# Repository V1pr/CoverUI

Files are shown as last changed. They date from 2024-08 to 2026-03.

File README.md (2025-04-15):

# CoverUI for [OpenMower](https://github.com/ClemensElflein/OpenMower)

 

## About

This repository contains the firmware files required to use the mowers CoverUI (ButtonBoard).

## Variants

1. Custom DIY CoverUI-PCB which replaces the stock (top-cover) PCB.<br>
 Please check the [Cover UI board assembly instructions](<https://openmower.de/docs/cover-ui-assembly/>) for more detailed infos.<br>
 Also available in [Vermut's Shop](https://shop.devops.care/10-openmower) (as part of his 'Upgrade Kit')
1. Stock YardForce CoverUI for the following models:
   1. Classic 500 (STM32 & GD32 MCU)
   2. Classic 500B (STM32 & GD32 MCU)
   3. SA/SC/NX-Type (10 Buttons, 12 LEDs), PCB labeled with RM-ECOW-V1.0.0 (STM32 MCU)
   4. SA/SC/NX-Type (9 Buttons, 11 LEDs), PCB labeled with RM-ECOW-V1.1.0 (STM32 & GD32 MCU)
   5. NX100i (18 Buttons, 3 LEDs, 256*64 Pixel LC-Display), PCB labeled with RM-EC3-V1.1 (STM32 MCU)
   6. SAxPro (Rev6) 6 Buttons 240*128 Pixel LC-Display (STM32 MCU)
   
    For this, you need to solder some cables and flash a modified firmware to it.<br>
    Please check the detailed [Stock CoverUI Readme](Firmware/CoverUI/YardForce/README.md) (as you've also the option to use your stock 'hall', 'stop' and 'rain' cables).

+1. LegacyHAT, a HAT addon for non-uC original CoverUI (9 Buttons, 11 LEDs), HAT uses an STM32F4xx "black pill" (mind the pill size!) - UNTESTED (yet!)

## License

Distributed under the MIT License. See [LICENSE](LICENSE) for more information.

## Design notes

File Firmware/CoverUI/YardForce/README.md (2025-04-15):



[][contributors-url]
[][forks-url]
[][stars-url]
[][issues-url]
[][license-url]

<!-- CoverUI model images -->
<br />
<div align="center">
  <a href="#hardware-modifications-by-model">
    Classic 500(B)
  </a>
  <a href="README-MOD-YF-SASCNX_RM-ECOW-V1.0.0.md">
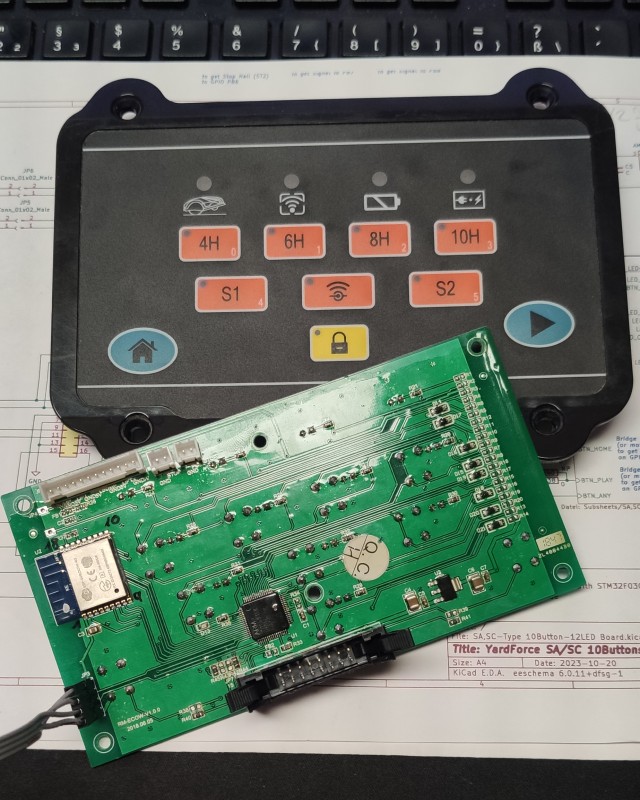
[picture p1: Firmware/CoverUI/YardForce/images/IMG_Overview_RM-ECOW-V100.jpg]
NX80i (10 Buttons, 12 LEDs) SA/SC/NX-Type CoverUI
    
  </a>
  <a href="README-MOD-YF-SASCNX_RM-ECOW-V1.1.0.md">
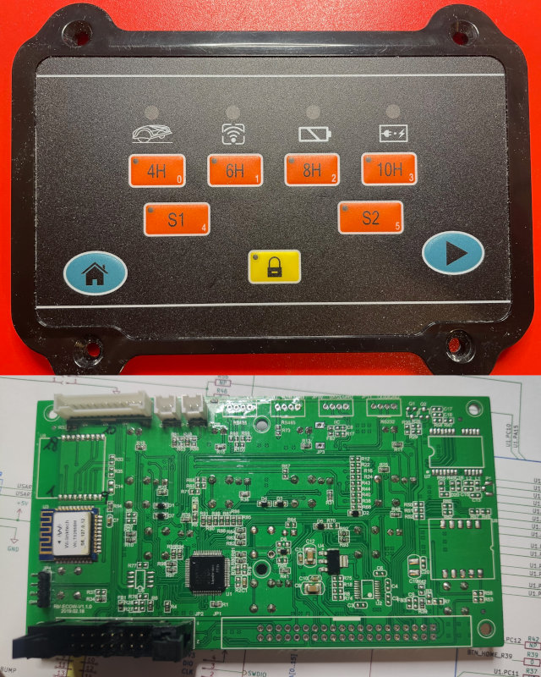
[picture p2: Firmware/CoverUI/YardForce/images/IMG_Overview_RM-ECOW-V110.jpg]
SA650 (9 Buttons, 11 LEDs) SA/SC/NX-Type CoverUI
    
  </a>
  <a href="README-MOD-YF-SASCNX_RM-EC3-V1.1.md">
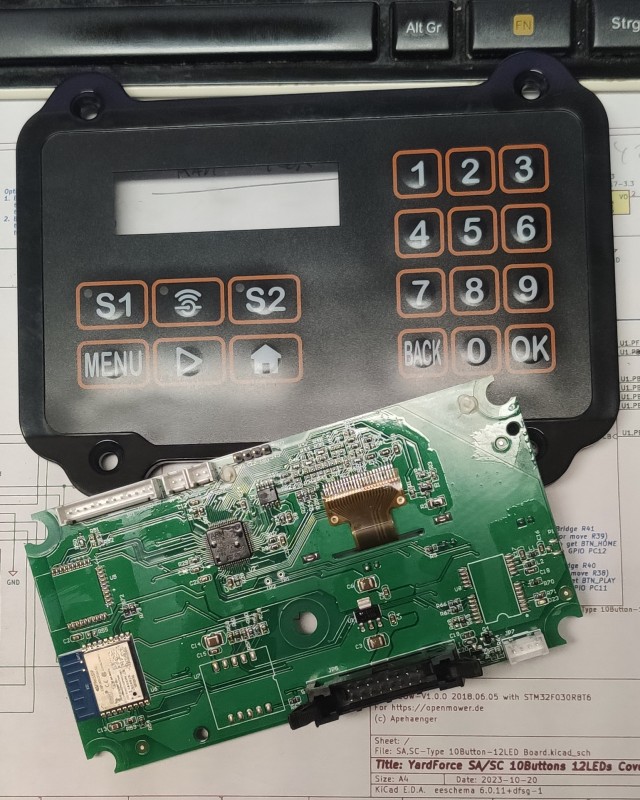
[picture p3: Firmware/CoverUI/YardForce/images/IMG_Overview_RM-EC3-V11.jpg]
NX100i (18 Buttons, 3 LEDs, 256*64 Pixel LC-Display) SA/SC/NX-Type CoverUI
    
  </a>
  <a href="README-MOD-YF-SASC_PRO_HS49067.md">
    SA/SC-PRO-Type (6 Buttons, 240*160 Pixel LC-Display)
  </a>

  <h3 align="center">OM CoverUI Firmware for Stock YardForce PCBs</h3>

  <p align="center">

#### Tested/working with

| YardForce Model | PCB Label | <a href="https://en.wikipedia.org/wiki/Microcontroller">MCU</a> Variant |
| :--- | :---: | :---: |
| Classic 500 | RM-ECOW-V1.3.0, 2020.05.08 | STM32F030R8, GD32F330R8 |
| Classic 500B | RM-ECOW-V1.3.1, 2021.08.09 | STM32F030R8[^1], GD32F330R8 |
| SA/SC/NX-Type (10 Buttons, 12 LEDs) | RM-ECOW-V1.0.0, 2018.06.05 | STM32F030R8 |
| SA/SC/NX-Type (9 Buttons, 11 LEDs)e | RM-ECOW-V1.1.0, 2019.02.18 | STM32F030R8, GD32F330R8 |
| NX100i (18 Buttons, 3 LEDs, 256*64 Pixel LC-Display), SA/SC/NX-Type | RM-EC3-V1.1, 20210619 | STM32F401RC |
| SA/SC-PRO-Type Rev6 (6 Buttons, 240*128 Pixel LC-Display) | HS49067, WYPCB319B | STM32F030RC |

  [^1]: Not yet tested, but it's expected that it will also work flawless

  </p>
</div>

## About The Project

For those, who still have their stock *YardForce (Rev6)* Cover-UI available and want to get it running together with [OpenMower](https://github.com/ClemensElflein/OpenMower), I ported OM's CoverUI <abbr title="Firmware">FW</abbr> functionality to a couple of them (see [Tested/working with](#testedworking-with)).

<p align="right">(<a href="#readme-top">back to top</a>)</p>

## Getting Started

### Prerequisites

* Compatible stock *YardForce* Cover-UI/Button-Board or Display (see [Tested/working with](#testedworking-with))
* Soldering Iron
* ST-Link programmer/debugger

### Hardware Modifications by Model

Every CoverUI model require some hardware modifications.

Please check here, what modifications are required for your CoverUI model:

- [YardForce Classic 500, RM-ECOW-V1.3.0](README-MOD-YF-C500_RM-ECOW-V1.3.0.md)
- [YardForce Classic 500**B**, RM-ECOW-V1.3.1](README-MOD-YF-C500B_RM-ECOW-V1.3.1.md)
- [YardForce SA/SC/NX-Type 10 Buttons, 12 LEDs, RM-ECOW-V1.0.0](README-MOD-YF-SASCNX_RM-ECOW-V1.0.0.md)
- [YardForce SA/SC/NX-Type 9 Buttons, 11 LEDs, RM-ECOW-V1.1.0](README-MOD-YF-SASCNX_RM-ECOW-V1.1.0.md)
- [YardForce NX100i (SA/SC/NX-Type) 18 Buttons, 3 LEDs, 256*64 Pixel LC-Display, RM-EC3-V1.1](README-MOD-YF-SASCNX_RM-EC3-V1.1.md)
- [YardForce SA/SC-PRO-Type 6 Buttons, 240*160 Dot-Matrix-Display, HS49067](README-MOD-YF-SASC_PRO_HS49067.md)

## Flash Firmware

### Programmer/Debugger

You need an ST-Link programmer/debugger like this cheap *ST-Link (V2) clone*:

My ST-Link (V2) clone

There're two generic ways to get the Firmware into your MCU.<br>
Either you flash the binary directly, or you compile it by yourself with [PlatformIO](https://platformio.org/).

### Firmware binaries

1. Goto [Releases](/releases)
2. Download `firmware-stock.zip`
3. Unpack it somewhere

The file name syntax of the included firmware binaries is:  `firmware_<MDL>_<MCU>[_<opt MOD>, ...].bin`

> **Warning**
> Only install the \<MOD> version, for which you also made the required hardware modifications!
> See [Hardware Modifications by Model](#hardware-modifications-by-model)

### ST-Link (flash binary)

> **Note**
> Updated 05/07/2023

It turns out that ST-Link GUI tool is some how flawy, why I recommend to use the `st-flash` console command.

Open a terminal/console, then:

* `st-info --descr` should return either:
  * `F0xx`, which identify your PCB's MCU as a 'STM32F030R8' (i.e. Classic 500)
  * `F1xx Medium-density` or `STM32F1xx_MD` which identify a 'GD32F330R8' MCU (i.e. Classic 500)
  * `F09X` identifies a 'STM32F030RC' MCU (i.e. SAxPRO Display)
* Unplug everything from you stock CoverUI PCB and connect your ST-Link to GND, CLK, DIO and 3V3. Take special attention to hit the '3.3V' pin of your ST-Link!! Now simply:<br>
 `st-flash write firmware_<mdl>_<mcu type>[_<opt mod>, ...].bin 0x08000000` which should log at the end something like 'Flash written and verified! jolly good!'

When done, re-plug your ST-Link and you should see a quick power-on animation.

If st-flash fails with an error like "Flash memory is write protected", we need to unlock it.<br>
I used [OpenOCD][OpenOCD-url] for unlocking it. Try `openocd --version` to check if [OpenOCD][OpenOCD-url] is already installed.

Unlock your flash via:

```openocd -f interface/stlink.cfg -f target/stm32f0x.cfg -c "init" -c "halt" -c "stm32f0x unlock 0" -c "shutdown"```

Now, try again flashing by: `st-flash write firmware_<mdl>_<mcu type>[_<opt mod>, ...].bin 0x08000000`

### PlatformIO

[PlatformIO](https://platformio.org/) is a [Visual Studio Code](https://code.visualstudio.com/) extension. Once installed, do:

- `PlatformIO` (left bar)
- `PIO Home` -> `Open`
- `Open Project` cloned repository branch -> CoverUI/Firmware/CoverUI (contains platformio.ini)
- Wait till tools got loaded (bottom right status info)
- In bottombar click `Switch PlatformIO Project Environment` and choose whatever MCU, MOD & programmer/debugger- probe you use
- Wait till tools got loaded (bottom right status info)
- Finally press `PlatformIO: Upload` (right arrow symbol) in bottombar. After it compiled, linked and uploaded, it should reboot and do a short power-on LED animation.
- If you get an "Error: stm32x device protected", simply upload a second time. Look like I placed the "unlock" command some how to late. 

<p align="right">(<a href="#readme-top">back to top</a>)</p>

<!-- USAGE EXAMPLES -->
## Usage

> **Note**
> Updated 11/07/2023

Once flashed, the CoverUI should show you a quick LED animation when powered on.

### Meaning of the LEDs:

| C500(B) | SA/SC/NX-Type,<br>9&nbsp;Buttons, 11&nbsp;LEDs | SA/SC/NX-Type,<br>10&nbsp;Buttons, 12&nbsp;LEDs | NX100i<br>(SA/SC/NX-Type),<br>18&nbsp;Buttons, 3&nbsp;LEDs,<br> 256*64 Pixel LC-Display | SA/SC-PRO<br>(240*160 Pixel LC-Display) | Remark |
| :-------: | :-----: | :-------: | :----: | :----: | ----- |
| 2hr&nbsp;-&nbsp;8hr | 4H&nbsp;-&nbsp;10H | 4H&nbsp;-&nbsp;10H | <img src="images/lcd.svg" width=15% height=15%> | <img src="images/lcd.svg" width=15% height=15%> | 4 digi GPS quality progressbar. Blink = No GPS-Fix
| S1 | :heavy_check_mark: | :heavy_check_mark: | <img src="images/brain-solid.svg" width=15% height=15%> | <img src="images/brain-solid.svg" width=15% height=15%> | ROS State:<br><b>On</b> = Running (idle)<br> <b>Blink-slow</b> = Autonomous mode (mowing, (un-)docking)<br><b>Blink-fast</b> = Area recording<br><b>Off</b> = ROS not running |
| S2 | :heavy_check_mark: | :heavy_check_mark: | <img src="images/lcd.svg" width=15% height=15%> | <img src="images/lcd.svg" width=15% height=15%> | ROS Sub-State:<br><b>On</b> = not used<br> <b>Blink-slow</b> = Docking or Record-Outline<br><b>Blink-fast</b> = Undocking or Record-Obstacle<br><b>Off</b> = Idle or Mowing |
| Lifted | :heavy_check_mark: | :heavy_check_mark: | <img src="images/car-burst-solid.svg" width=15% height=15%> | <img src="images/car-burst-solid.svg" width=15% height=15%> | Emergency:<br><b>On</b> = No heart beat for more than 0.5s?!?<br> <b>Blink-slow</b> = Lifted or tilted<br><b>Blink-fast</b> = Stop button pressed<br><b>Off</b> = No Emergency |
| Wire | WLAN | WLAN | <img src="images/satellite-dish-solid.svg" width=15% height=15%> | <img src="images/satellite-dish-solid.svg" width=15% height=15%> | GPS Quality:<br><b>On</b> = \<25%<br><b>Blink-fast</b> = \<50%<br><b>Blink-slow</b> = \<75%<br><b>Off</b> = \>75% |
| Battery | :heavy_check_mark: | :heavy_check_mark: | <img src="images/car-battery-solid.svg" width=15% height=15%> | <img src="images/car-battery-solid.svg" width=15% height=15%> | <b>On</b> = Empty |
| Charge | :heavy_check_mark: | :heavy_check_mark: | <img src="images/charging-station-solid.svg" width=15% height=15%> | <img src="images/charging-station-solid.svg" width=15% height=15%> | <b>On</b> = Fully charged<br><b>Blink-slow</b> = Approx. 50% charged<br><b>Blink-fast</b> = Empty<br><b>Off</b> = Not docked |
| Mon-Sun | :x: | :x: | <img src="images/lcd.svg" width=15% height=15%> | <img src="images/lcd.svg" width=15% height=15%> | 7 digit battery-charge-state progress bar |

### Button usage:

| C500(B) | SA/SC/NX-Type,<br>9&nbsp;Buttons, 11&nbsp;LEDs | SA/SC/NX-Type,<br>10&nbsp;Buttons, 12&nbsp;LEDs | NX100i (SA/SC/NX-Type),<br>18&nbsp;Buttons, 3&nbsp;LEDs,<br> 256*64 Pixel LC-Display | SA/SC-PRO<br>(240*160 Pixel LC-Display) | Remark |
| :-------: | :----: | :---------------------------------: | :-----: | :----: | ----- |
| <kbd>Home</kbd> | :heavy_check_mark: | :heavy_check_mark: | :heavy_check_mark: | :heavy_check_mark: | Go home (docking station) |
| <kbd>▶</kbd> | :heavy_check_mark: | :heavy_check_mark: | :heavy_check_mark: | <kbd>Start</kbd> | Start mowing or continue |
| <kbd>S1</kbd> | :heavy_check_mark: | :heavy_check_mark: | :heavy_check_mark: | :x: | Start area recording if 'idle'. Pause if 'mowing' |
| <kbd>S2</kbd> | :heavy_check_mark: | :heavy_check_mark: | :heavy_check_mark: | :x: | Skip over to next area if 'mowing'. Long press (2-3s) in 'idle', delete all recorded areas! |
| <kbd>Lock</kbd> | :heavy_check_mark: | :heavy_check_mark: | :x: | <kbd>Enter</kbd> | Long press (2-3s) reset emergency |
| <kbd>OK</kbd>+<kbd>Sun</kbd> | <kbd>Lock</kbd>+<kbd>10H</kbd> | <kbd>Setup</kbd>+<kbd>10H</kbd> | <kbd>MENU</kbd>+<kbd>BACK</kbd> | :x: | Trigger power-on animation.<br>This is mainly for mounting validation, to ensure that you hit all LED guidance holes |
| <kbd>OK</kbd>+<kbd>Clock</kbd> | <kbd>Lock</kbd>+<kbd>4H</kbd> | <kbd>Setup</kbd>+<kbd>4H</kbd> | <kbd>MENU</kbd>+<kbd>0</kbd> | :x: | Display CoverUI- firmware version. LED only models will show the version as a number sequence[^2], which should show (as of writing) 206 |
| <kbd>Mon</kbd> | <kbd>4H</kbd> | <kbd>4H</kbd> | <kbd>1</kbd> | <img src="images/circle-up-solid.svg" width=20% height=20%> | Volume up[^3] |
| <kbd>Tue</kbd> | <kbd>6H</kbd> | <kbd>6H</kbd> | <kbd>2</kbd> | <img src="images/circle-down-solid.svg" width=20% height=20%> | Volume down[^3] |
| <kbd>Wed</kbd> | :x: | <kbd>8H</kbd> | <kbd>3</kbd> | <kbd>Back</kbd> | ~~Next language~~ Language selection has moved to mower_config[^3] |

[^2]: A 'number sequence' get displayed via the 'Mon(0)' to 'Sun(6)' or '4H(0)' to 'S2(5)' LEDs, whereas every short blinking 'Lifted' LED indicate a new digit.
Larger digits, get displayed with multiple digit LEDs.
I.e. 9 = 'Sun(6)' together with 'Thu(3)'

[^3]: 'Improve-Sound' branch  of 'OpenMower' Pico Firmware presupposed

<p align="right">(<a href="#readme-top">back to top</a>)</p>

## Final work

Lastly, for connecting you CoverUI, you need a cable to plug it into OM's Mainboard "UI Board" connector.

I simply cropped the 16 pin connector from my original cable and crimped OM's plug.

<span style="color:red;">But before blindly doing it, validate if the cables pin 1 mark, also matches the 16 pin female/male connector!</span>

![Cable](images/IMG_Cable.jpg)

You're done!

Plug it into `UI Board` connector of your OM mainboard and
check section [usage](#usage) about the [LED](#meaning-of-the-leds) and [Button](#button-usage) usage.

## Version History

| Version [^4] | Changes | Date |
| ------- | ------- | ---- |
| 2.06    | - Add MOD_HALL support to YardForce RM-ECOW-V1.0.0<br>- Fix heap overflow which could happen when an action button got pressed multiple (10-20) times | 2024-09-29
| 2.05    | - YardForce RM-ECOW-V1.1.0 support<br>- Backside alive LED is now software driven (hwtimer independent)<br>- Fix emergency-clear LED-countdown for RM-ECOW-V1.0.0| 2024-06-30
| 2.04    | - YardForce RM-ECOW-V1.0.0 support<br>- Dropped separate versioning<br>- Fully refactored | 2023-11-14
| 1.00    | - YardForce SAxPRO (Rev6) Dot-Matrix-Display support | 2023-09-27
| 1.00    | - Stock-Cable support for rain & hall sensors<br>- Classic 500B support | 2023-05-13
|  NA       | First OM's CoverUI port for YardForce Classic 500 | 2023-05-01

[^4]: Press sys-req button combo 'Display CoverUI- firmware version' (see [Button Usage](#button-usage)) to get your installed FW version displayed

<!-- CONTRIBUTING -->
## Contributing

Contributions are what make the open source community such an amazing place to learn, inspire, and create. Any contributions you make are **greatly appreciated**.

If you have a suggestion that would make this better, please fork the repo and create a pull request. You can also simply open an issue with the tag "enhancement".
Don't forget to give the project a star! Thanks again!

1. Fork the Project
2. Create your Feature Branch (`git checkout -b feature/AmazingFeature`)
3. Commit your Changes (`git commit -m 'Add some AmazingFeature'`)
4. Push to the Branch (`git push origin feature/AmazingFeature`)
5. Open a Pull Request

<p align="right">(<a href="#readme-top">back to top</a>)</p>

<!-- LICENSE -->
## License

Distributed under the MIT License. See `LICENSE.txt` for more information.

<p align="right">(<a href="#readme-top">back to top</a>)</p>

<!-- ACKNOWLEDGMENTS -->
## Acknowledgments

* [OpenMower](https://github.com/ClemensElflein/OpenMower)
* [Mowgli](https://github.com/cloudn1ne/Mowgli)
* [PlatformIO](https://platformio.org/)

<p align="right">(<a href="#readme-top">back to top</a>)</p>

<!-- MARKDOWN LINKS & IMAGES -->
<!-- https://www.markdownguide.org/basic-syntax/#reference-style-links -->
[contributors-shield]: https://img.shields.io/github/contributors/ClemensElflein/CoverUI.svg?style=for-the-badge
[contributors-url]: https://github.com/ClemensElflein/CoverUI/graphs/contributors
[forks-shield]: https://img.shields.io/github/forks/ClemensElflein/CoverUI.svg?style=for-the-badge
[forks-url]: https://github.com/ClemensElflein/CoverUI/network/members
[stars-shield]: https://img.shields.io/github/stars/ClemensElflein/CoverUI.svg?style=for-the-badge
[stars-url]: https://github.com/ClemensElflein/CoverUI/stargazers
[issues-shield]: https://img.shields.io/github/issues/ClemensElflein/CoverUI.svg?style=for-the-badge
[issues-url]: https://github.com/ClemensElflein/CoverUI/issues
[license-shield]: https://img.shields.io/github/license/ClemensElflein/CoverUI.svg?style=for-the-badge
[license-url]: https://github.com/ClemensElflein/CoverUI/blob/master/LICENSE.txt
[OpenOCD-url]: https://openocd.org/pages/about.html

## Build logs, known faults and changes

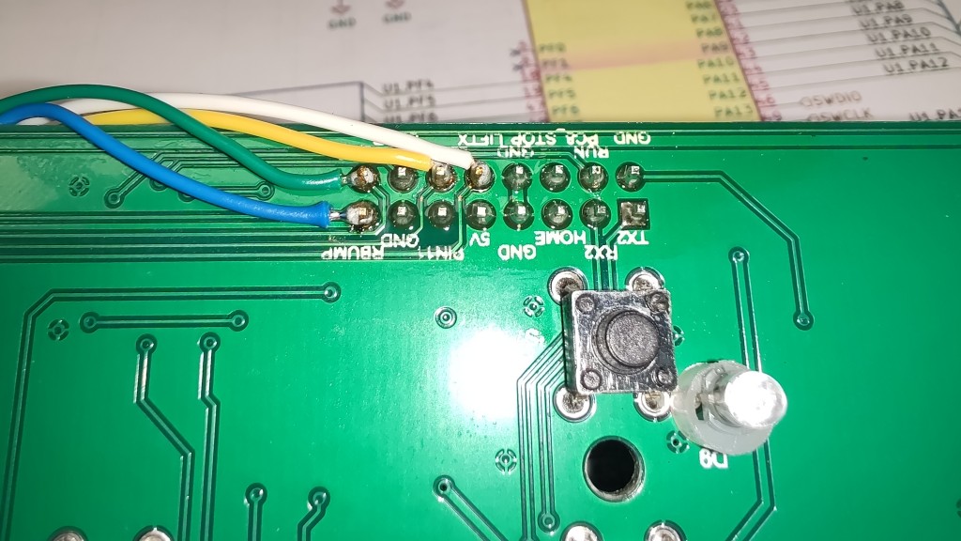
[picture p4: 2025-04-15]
Firmware/CoverUI/YardForce/images/IMG_PCB_Changes_RM-ECOW-V100_Hall.jpg

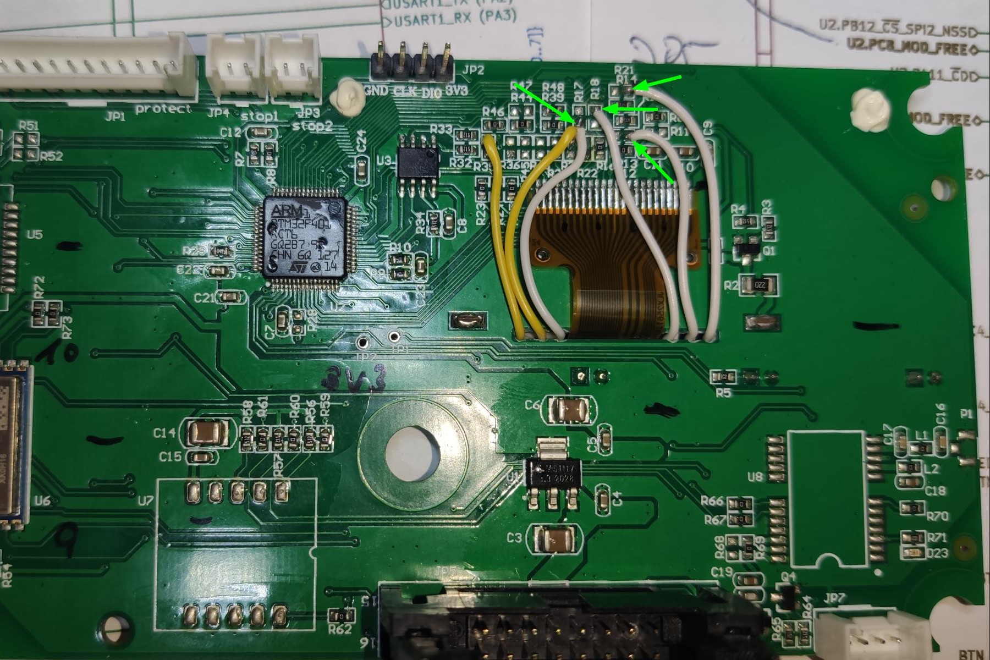
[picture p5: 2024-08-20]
Firmware/CoverUI/YardForce/images/IMG_PCB_Changes_RM-EC3-V11_Hall2.jpg

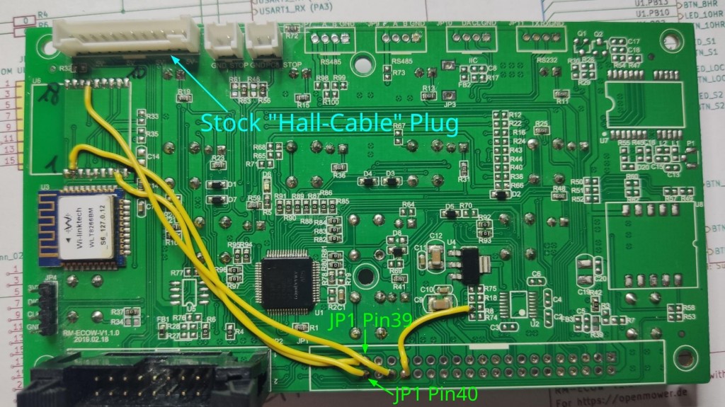
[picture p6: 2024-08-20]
Firmware/CoverUI/YardForce/images/IMG_PCB_Changes_RM-ECOW-V110_Hall.jpg

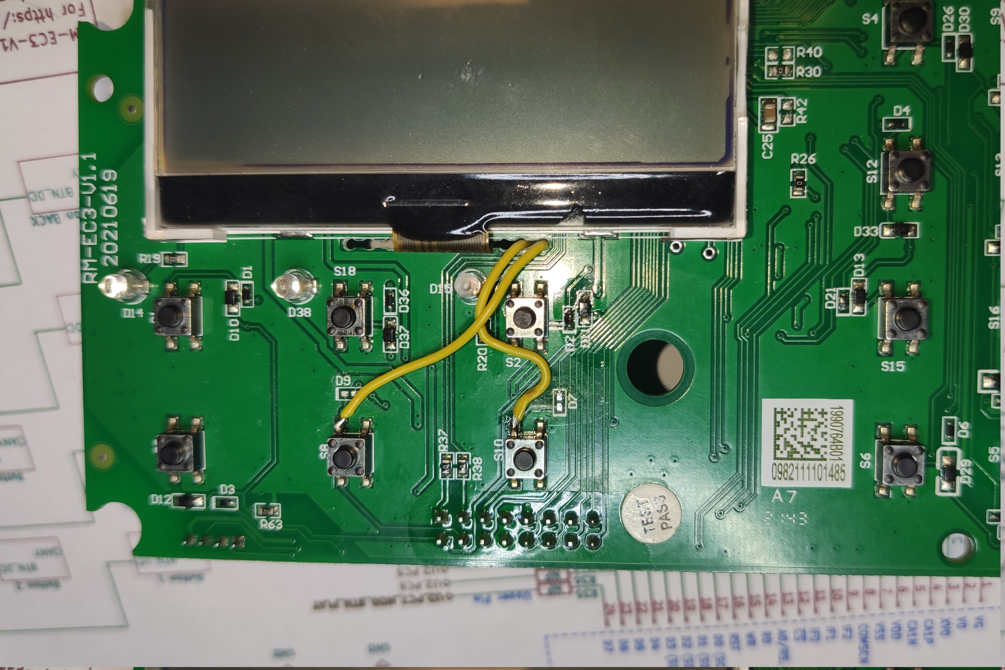
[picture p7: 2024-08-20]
Firmware/CoverUI/YardForce/images/IMG_PCB_Changes_RM-EC3-V11_Mandatory1.jpg

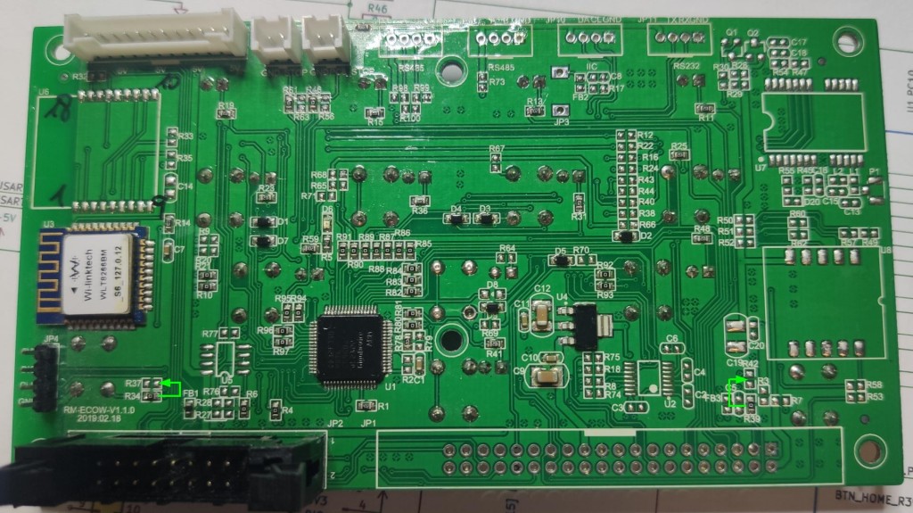
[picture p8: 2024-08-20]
Firmware/CoverUI/YardForce/images/IMG_PCB_Changes_RM-ECOW-V110_Buttons.jpg

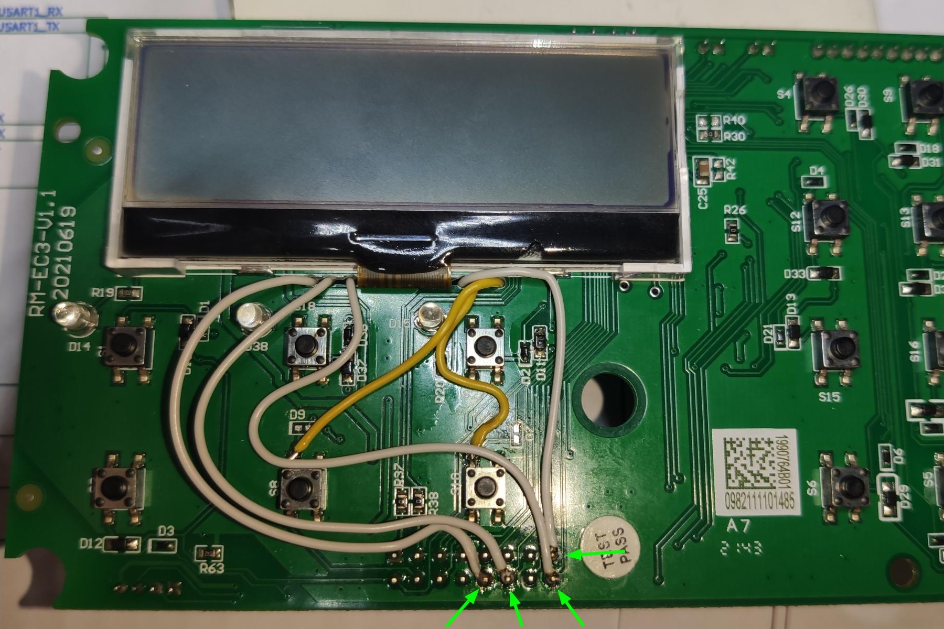
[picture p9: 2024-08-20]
Firmware/CoverUI/YardForce/images/IMG_PCB_Changes_RM-EC3-V11_Hall1.jpg

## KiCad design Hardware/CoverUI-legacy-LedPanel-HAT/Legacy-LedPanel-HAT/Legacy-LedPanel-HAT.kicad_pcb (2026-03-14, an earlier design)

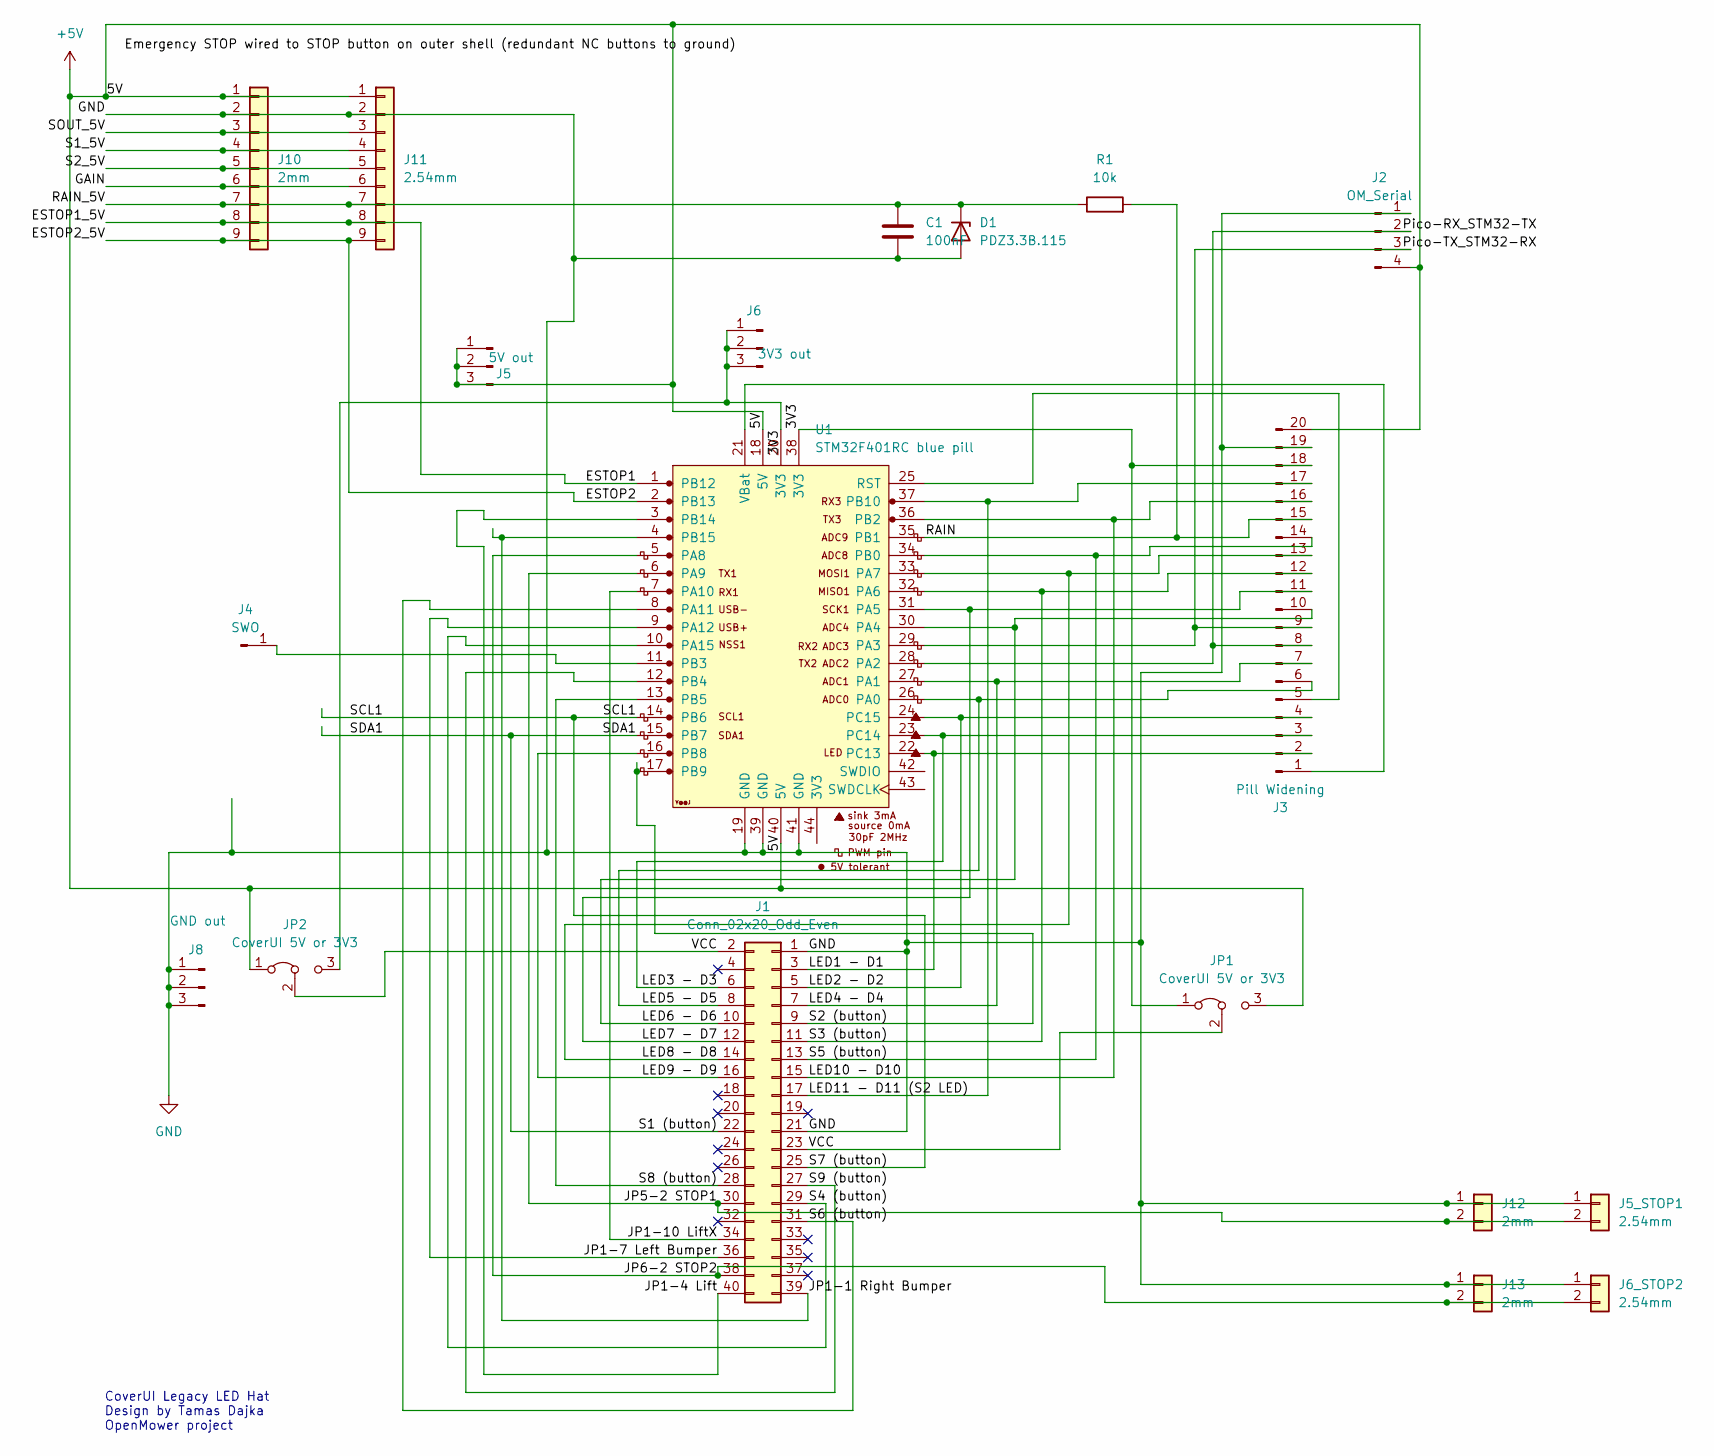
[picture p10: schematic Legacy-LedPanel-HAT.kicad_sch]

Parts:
C1: 100nF; C_1812_4532Metric
D1: PDZ3.3B.115; D_1812_4532Metric
J1: Conn_02x20_Odd_Even; PinHeader_2x20_P2.54mm_Vertical
J2: OM_Serial; JST_XH_S4B-XH-A_1x04_P2.50mm_Horizontal
J3: Pill Widening; PinHeader_1x20_P2.54mm_Vertical
J4: SWO; PinHeader_1x01_P2.54mm_Vertical
J5: 5V out; PinHeader_1x03_P2.54mm_Vertical
J5_STOP1, J6_STOP2: 2.54mm; JST_XH_B2B-XH-A_1x02_P2.50mm_Vertical
J6: 3V3 out; PinHeader_1x03_P2.54mm_Vertical
J8: GND out; PinHeader_1x03_P2.54mm_Vertical
J10: 2mm; JST_PH_B9B-PH-K_1x09_P2.00mm_Vertical
J11: 2.54mm; JST_XH_B9B-XH-A_1x09_P2.50mm_Vertical
J12, J13: 2mm; JST_PH_B2B-PH-K_1x02_P2.00mm_Vertical
JP1, JP2: CoverUI 5V or 3V3; PinHeader_1x03_P2.54mm_Vertical
R1: 10k; R_1812_4532Metric_Pad1.30x3.40mm_HandSolder
U1: STM32F401RC blue pill; YAAJ_WeAct_BlackPill_SWD_2

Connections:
+5V: J2.4, J3.20, J5.1, J5.2, J5.3, J10.1, J11.1, JP1.3 (B), JP2.1 (A), U1.18 (5V), U1.40 (5V)
/3V3: J3.18, J6.1, J6.2, J6.3, JP1.1 (A), JP2.3 (B), U1.20 (3V3), U1.38 (3V3)
/ESTOP1: J10.8, J11.8, U1.1 (PB12)
/ESTOP2: J10.9, J11.9, U1.2 (PB13)
/GAIN: J10.6, J11.6
/JP1-1 Right Bumper: J1.39, U1.4 (PB15)
/JP1-4 Lift: J1.40, U1.3 (PB14)
/JP1-7 Left Bumper: J1.36, U1.9 (PA12)
/JP1-10 LiftX: J1.34, U1.7 (PA10)
/JP5-2 STOP1: J1.30, J5_STOP1.2, J12.2, U1.6 (PA9)
/JP6-2 STOP2: J1.38, J6_STOP2.2, J13.2, U1.5 (PA8)
/LED1 - D1: J1.3, J3.2, U1.22 (PC13)
/LED2 - D2: J1.5, J3.4, U1.24 (PC15)
/LED3 - D3: J1.6, J3.3, U1.23 (PC14)
/LED4 - D4: J1.7, J3.7, U1.27 (PA1)
/LED5 - D5: J1.8, J3.6, U1.26 (PA0)
/LED6 - D6: J1.10, J3.10, U1.30 (PA4)
/LED7 - D7: J1.12, J3.11, U1.31 (PA5)
/LED8 - D8: J1.14, J3.13, U1.33 (PA7)
/LED9 - D9: J1.16, U1.16 (PB8)
/LED10 - D10: J1.15, J3.16, U1.36 (PB2)
/LED11 - D11 (S2 LED): J1.17, J3.17, U1.37 (PB10)
/Pico-RX_STM32-TX: J2.2, J3.8, U1.28 (PA2)
/Pico-TX_STM32-RX: J2.3, J3.9, U1.29 (PA3)
/RAIN: J3.15, R1.2, U1.35 (PB1)
/RAIN_5V: C1.1, D1.1 (K), J10.7, J11.7, R1.1
/S1 (button): J1.22, U1.15 (PB7)
/S1_5V: J10.4, J11.4
/S2 (button): J1.9, U1.17 (PB9)
/S2_5V: J10.5, J11.5
/S3 (button): J1.11, J3.12, U1.32 (PA6)
/S4 (button): J1.29, U1.10 (PA15)
/S5 (button): J1.13, J3.14, U1.34 (PB0)
/S6 (button): J1.31, U1.8 (PA11)
/S7 (button): J1.25, U1.14 (PB6)
/S8 (button): J1.28, U1.13 (PB5)
/S9 (button): J1.27, U1.12 (PB4)
/SOUT_5V: J10.3, J11.3
/VCC: J1.2, J1.23, JP1.2 (C), JP2.2 (C)
GND: C1.2, D1.2 (A), J1.1, J1.21, J2.1, J3.19, J5_STOP1.1, J6_STOP2.1, J8.1, J8.2, J8.3, J10.2, J11.2, J12.1, J13.1, U1.19 (GND), U1.39 (GND), U1.41 (GND)
unnamed: J3.1, U1.21 (VBat)
unnamed: J3.5, U1.25 (RST)
unnamed: J4.1, U1.11 (PB3)

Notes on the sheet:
CoverUI Legacy LED Hat Design by Tamas Dajka OpenMower project

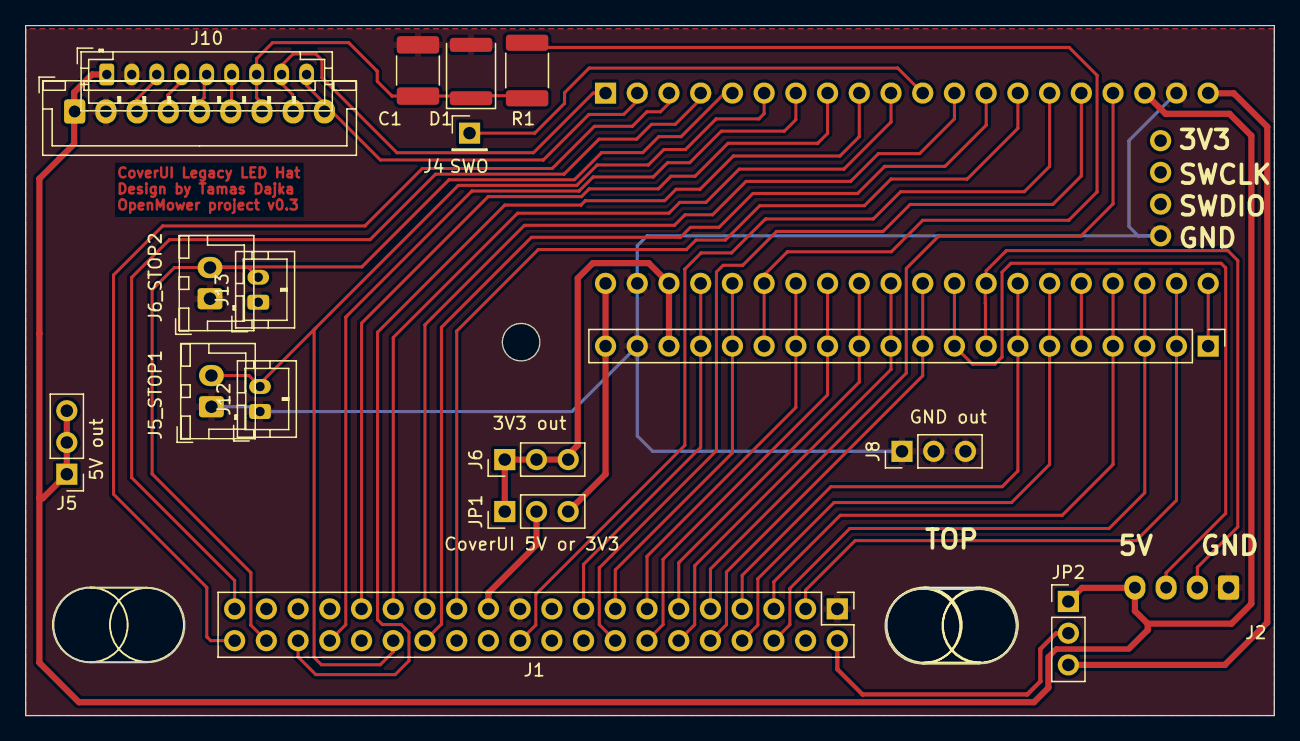
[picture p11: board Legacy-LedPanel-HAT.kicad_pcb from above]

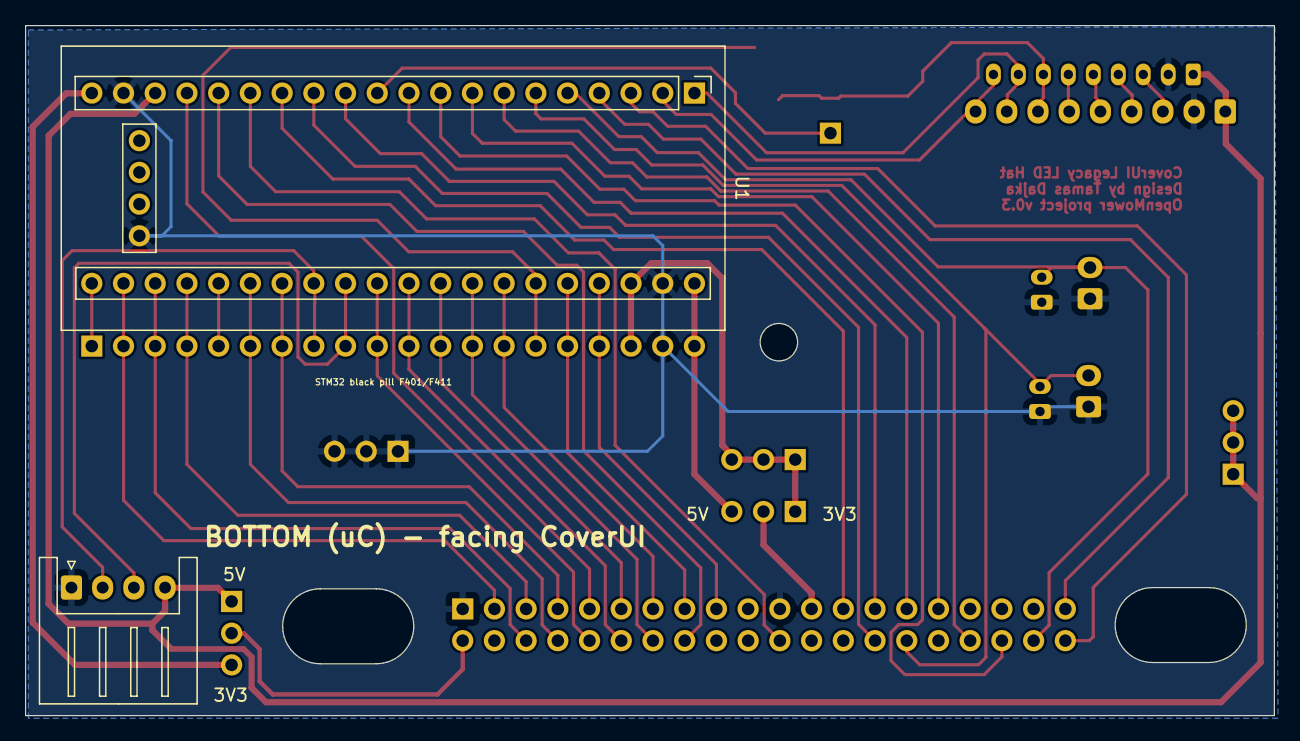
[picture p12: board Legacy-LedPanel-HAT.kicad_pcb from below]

Board: 2 copper layers, 100.0 x 55.3 mm, 19 parts (2 on the bottom side), 43 nets.

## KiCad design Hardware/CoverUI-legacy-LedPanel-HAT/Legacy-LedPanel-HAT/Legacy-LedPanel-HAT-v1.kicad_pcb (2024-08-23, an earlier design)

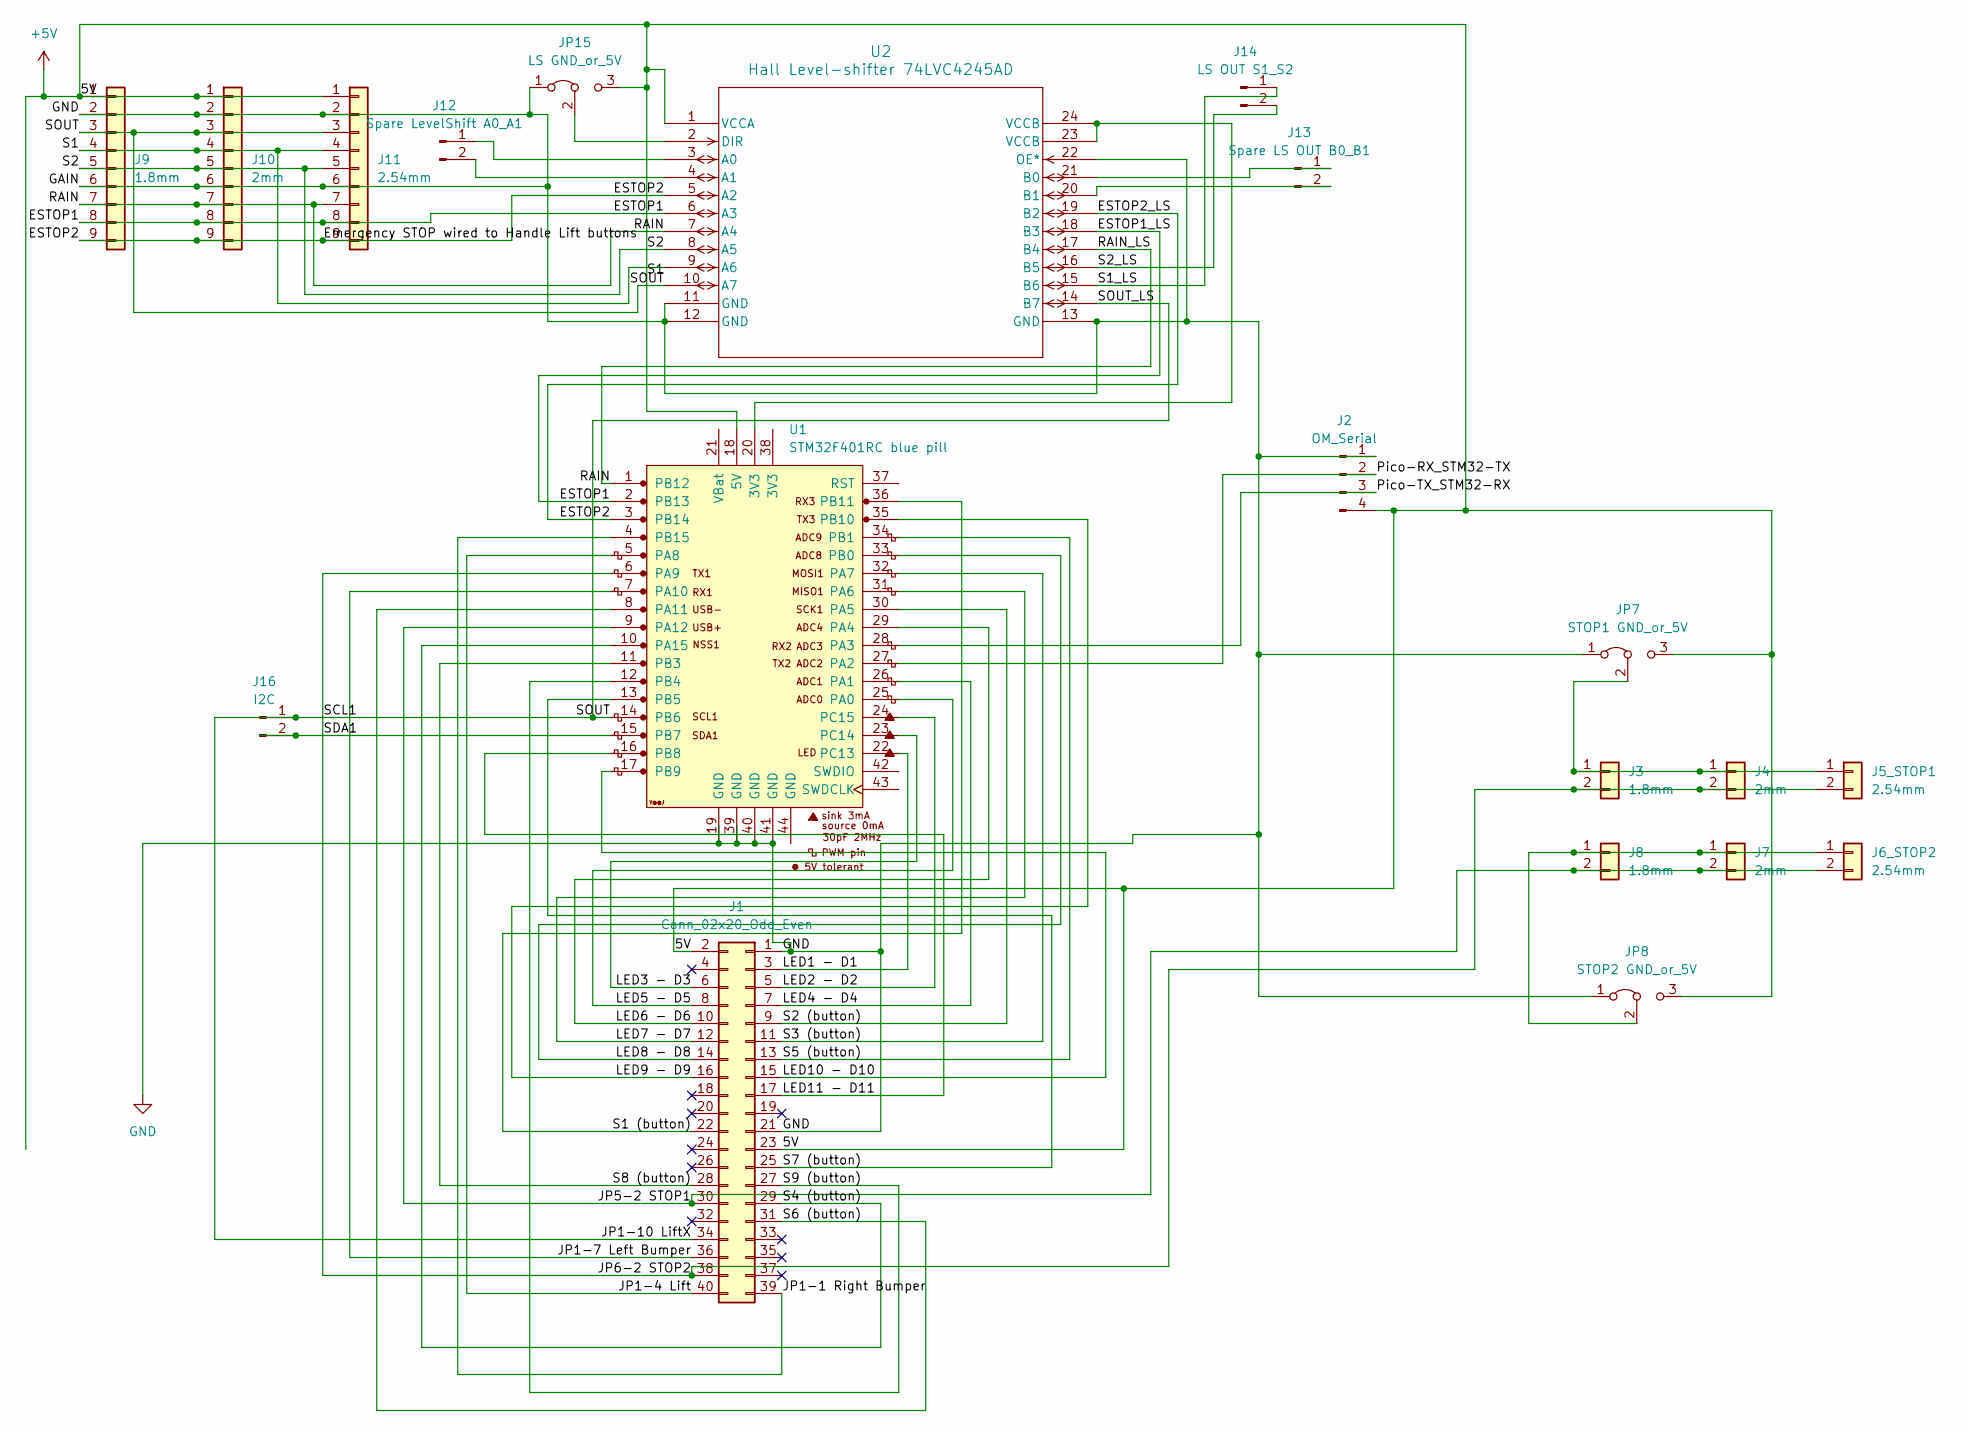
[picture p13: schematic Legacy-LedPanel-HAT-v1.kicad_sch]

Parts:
J1: Conn_02x20_Odd_Even; PinHeader_2x20_P2.54mm_Vertical
J2: OM_Serial; JST_XH_S4B-XH-A_1x04_P2.50mm_Horizontal
J3, J8: 1.8mm; conn_01x2_1.8mm
J4, J7: 2mm; JST_PH_B2B-PH-K_1x02_P2.00mm_Vertical
J5_STOP1, J6_STOP2: 2.54mm; JST_XH_B2B-XH-A_1x02_P2.50mm_Vertical
J9: 1.8mm; conn_01x9_1.8mm
J10: 2mm; JST_PH_S9B-PH-K_1x09_P2.00mm_Horizontal
J11: 2.54mm; JST_XH_S9B-XH-A-1_1x09_P2.50mm_Horizontal
J12: Spare LevelShift A0_A1; PinHeader_1x02_P2.54mm_Horizontal
J13: Spare LS OUT B0_B1; PinHeader_1x02_P2.54mm_Horizontal
J14: LS OUT S1_S2; PinHeader_1x02_P2.54mm_Horizontal
J16: I2C; PinHeader_1x02_P2.54mm_Horizontal
JP7: STOP1 GND_or_5V; PinHeader_1x03_P2.54mm_Vertical
JP8: STOP2 GND_or_5V; PinHeader_1x03_P2.54mm_Vertical
JP15: LS GND_or_5V; PinHeader_1x03_P2.54mm_Vertical
U1: STM32F401RC blue pill; YAAJ_BluePill_SWD_1
U2: Hall Level-shifter 74LVC4245AD; SOT137-1_NEX

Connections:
+5V: J1.2, J1.23, J2.4, J9.1, J10.1, J11.1, JP7.3 (B), JP8.3 (B), JP15.3 (B), U1.18 (5V), U2.1 (VCCA)
/ESTOP1: J9.8, J10.8, J11.8, U1.2 (PB13), U2.6 (A3), U2.18 (B3)
/ESTOP2: J9.9, J10.9, J11.9, U1.3 (PB14), U2.5 (A2), U2.19 (B2)
/JP1-1 Right Bumper: J1.39, U1.4 (PB15)
/JP1-4 Lift: J1.40, U1.5 (PA8)
/JP1-7 Left Bumper: J1.36, U1.7 (PA10)
/JP5-2 STOP1: J1.30, J6_STOP2.2, J7.2, J8.2, U1.9 (PA12)
/LED1 - D1: J1.3, U1.22 (PC13)
/LED2 - D2: J1.5, U1.24 (PC15)
/LED3 - D3: J1.6, U1.23 (PC14)
/LED4 - D4: J1.7, U1.26 (PA1)
/LED5 - D5: J1.8, U1.25 (PA0)
/LED6 - D6: J1.10, U1.29 (PA4)
/LED7 - D7: J1.12, U1.31 (PA6)
/LED8 - D8: J1.14, U1.33 (PB0)
/LED9 - D9: J1.16, U1.35 (PB10)
/LED10 - D10: J1.15, U1.17 (PB9)
/LED11 - D11: J1.17, U1.16 (PB8)
/Pico-RX_STM32-TX: J2.2, U1.27 (PA2)
/Pico-TX_STM32-RX: J2.3, U1.28 (PA3)
/RAIN: J9.7, J10.7, J11.7, U1.1 (PB12), U2.7 (A4), U2.17 (B4)
/S1: J9.4, J10.4, J11.4, U2.9 (A6)
/S1 (button): J1.22, U1.36 (PB11)
/S1_LS: J14.1, U2.15 (B6)
/S2: J9.5, J10.5, J11.5, U2.8 (A5)
/S2 (button): J1.9, U1.30 (PA5)
/S2_LS: J14.2, U2.16 (B5)
/S3 (button): J1.11, U1.32 (PA7)
/S4 (button): J1.29, U1.10 (PA15)
/S5 (button): J1.13, U1.34 (PB1)
/S6 (button): J1.31, U1.8 (PA11)
/S7 (button): J1.25, U1.13 (PB5)
/S8 (button): J1.28, U1.11 (PB3)
/S9 (button): J1.27, U1.12 (PB4)
GND: J1.1, J1.21, J2.1, J9.2, J9.6, J10.2, J10.6, J11.2, J11.6, JP7.1 (A), JP8.1 (A), JP15.1 (A), U1.19 (GND), U1.39 (GND), U1.40 (GND), U1.41 (GND), U2.11 (GND), U2.12 (GND), U2.13 (GND), U2.22 (OE*)
unnamed: J3.1, J4.1, J5_STOP1.1, JP7.2 (C)
unnamed: J6_STOP2.1, J7.1, J8.1, JP8.2 (C)
unnamed: J12.1, U2.3 (A0)
unnamed: J12.2, U2.4 (A1)
unnamed: J13.1, U2.21 (B0)
unnamed: J13.2, U2.20 (B1)
unnamed: JP15.2 (C), U2.2 (DIR)
unnamed: U1.20 (3V3), U2.23 (VCCB), U2.24 (VCCB)

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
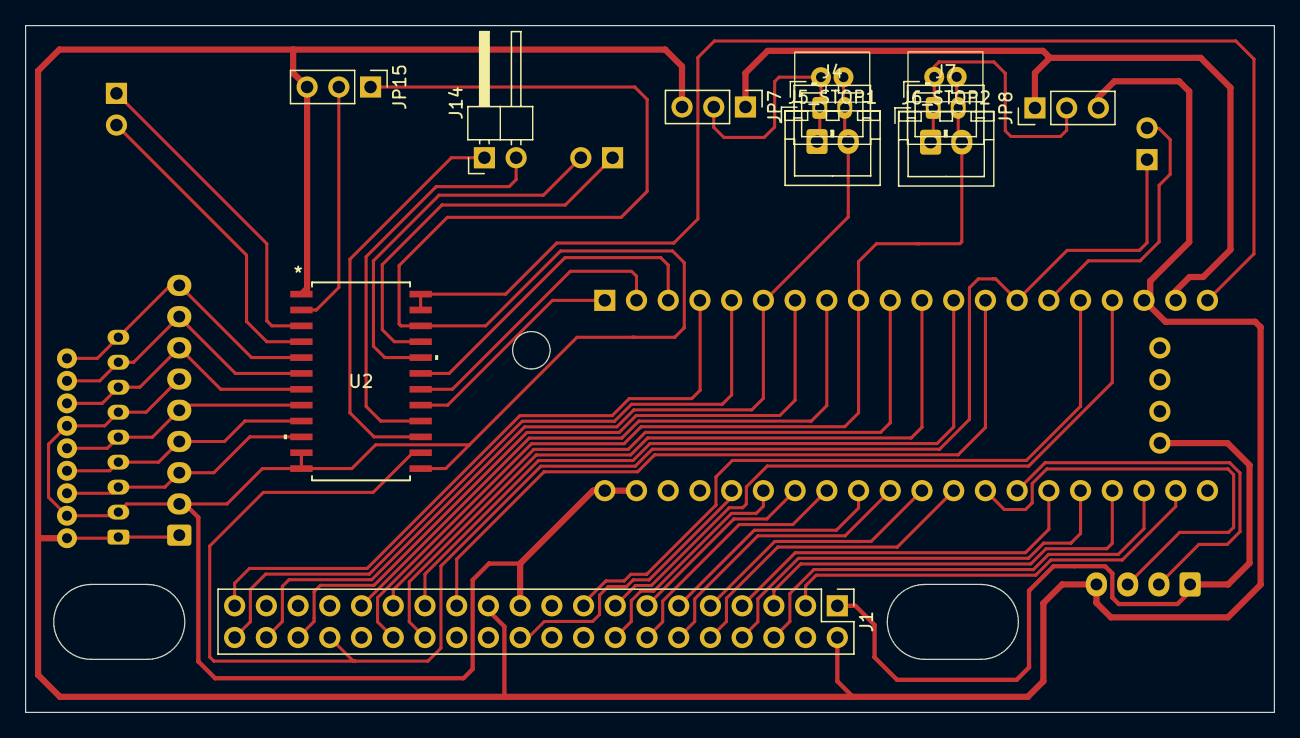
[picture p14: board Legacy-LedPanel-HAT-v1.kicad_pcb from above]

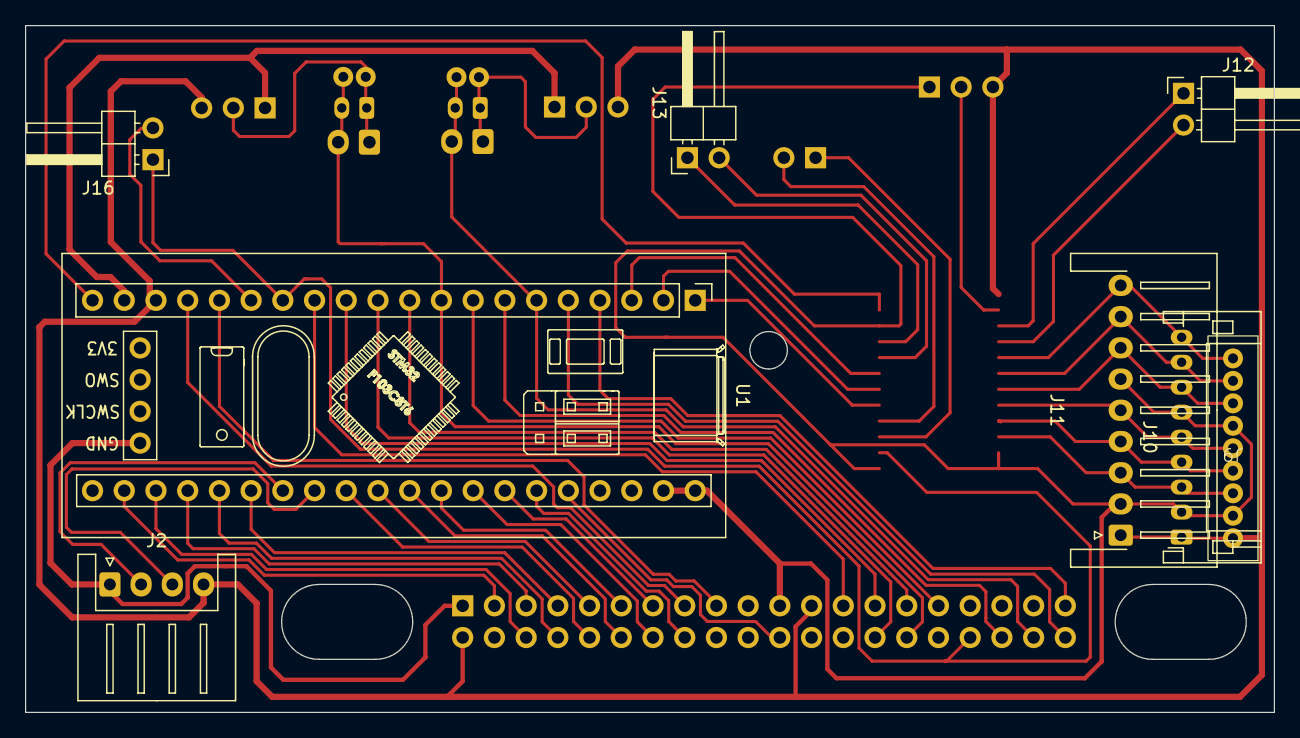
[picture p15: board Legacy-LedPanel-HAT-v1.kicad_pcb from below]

Board: 2 copper layers, 100.0 x 55.0 mm, 20 parts (8 on the bottom side), 46 nets.

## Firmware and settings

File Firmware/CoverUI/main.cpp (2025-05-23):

// control to print out serial information in debug state via usb serial
// #define _serial_debug_

#include <stdio.h>

#define FIRMWARE_VERSION 200
// V 2.00 v. 11.10.2022 new protocol implementation for less messages on the bus

#ifdef HW_YF // Stock YardForce HardWare
#include "YardForce/include/main.h"
extern bool first_byte_recv;
#else // OM's Pico based HardWare
#include "pico/stdlib.h"
#include "hardware/pio.h"
#include "hardware/clocks.h"
#include "pico/multicore.h"
#include "hardware/uart.h"
#include "hardware/irq.h"
#endif
#include <cstdio>
#include "COBS.h"
#ifdef CRC // i.e. defined by STM32 HAL or STM32 CMSIS
#undef CRC
#endif
#include "CRC.h" // TODO STM32: might/should use STM32 embedded crc unit

#include <cstring>

#ifndef HW_YF // HW Pico

#include "LEDcontrol.h"
#include "statemachine.h"
#include "buttonscan.h"
#endif
#include "BttnCtl.h"

#define bufflen 1000

// buzzer ontime in ms
#define shortbeep 50

// 2cnd UART
#define UART_1 uart1
#define BAUD_RATE 115200
#define UART_TX_PIN 4
#define UART_RX_PIN 5

// write & read pointer serial interrupt buffer
static unsigned int write = 0;

// serial buffer
static uint8_t buffer_serial[bufflen];
// count values in COBS-Buffer
static uint8_t decoded_buffer[bufflen];
// buffer for encoded output messages
static uint8_t out_buf[bufflen];

COBS cobs;

// defintion PIO-block and uses statemachines
PIO pio_Block1 = pio0;
PIO pio_Block2 = pio1;
int sm_blink;  // Statemachine onboard LED blinking
int sm_LEDmux; // Statemachine control LEDSs
int sm_buzz;   // Statemachine control Buzzer

auto_init_mutex(mx1);

/****************************************************************************************************
 *
 * interface to the statemachine, control buzzer
 *
 *****************************************************************************************************/

void Buzzer_set(uint32_t anz, uint32_t timeON, uint32_t timeOFF)
{
  mutex_enter_blocking(&mx1);
  buzzer_program_put_words(pio_Block2, sm_buzz, anz, timeON * buzzer_SM_CYCLE / 4000, timeOFF);
  mutex_exit(&mx1);
}

/****************************************************************************************************
 *
 * sendMessage send the command strucutre via COBS and serial Port and wait for reply
 *
 *****************************************************************************************************/

void sendMessage(void *message, size_t size)
{
  mutex_enter_blocking(&mx1);

  // packages need to be at least 1 byte of type, 1 byte of data and 2 bytes of CRC
  if (size < 4)
  {
    mutex_exit(&mx1);
    return;
  }

  uint8_t *data_pointer = (uint8_t *)message;
  uint16_t *crc_pointer = (uint16_t *)(data_pointer + (size - 2));

  // calculate the CRC
  *crc_pointer = CRC::Calculate(message, size - 2, CRC::CRC_16_CCITTFALSE());
  // structure is filled and CRC calculated, so print out, what should be encoded

#ifdef _serial_debug_
  printf("\nprint struct before encoding %d byte : ", (int)size);
  uint8_t *temp = data_pointer;
  for (size_t i = 0; i < size; i++)
  {
    printf("0x%02x , ", *temp);
    temp++;
  }
#endif

  // encode message

  size_t encoded_size = cobs.encode((uint8_t *)message, size, out_buf);
  out_buf[encoded_size] = 0;
  encoded_size++;

#ifdef _serial_debug_
  printf("\nencoded message              %d byte : ", (int)encoded_size);
  for (unsigned int i = 0; i < encoded_size; i++)
  {
    printf("0x%02x , ", out_buf[i]);
  }
#endif

  for (unsigned int i = 0; i < encoded_size; i++)
  {
    uart_putc(UART_1, out_buf[i]);
  }
  mutex_exit(&mx1);
}

/****************************************************************************************************
 *
 * PacketReceived() there is a serial stream in the buffer
 * decode it with cobs, calc crc and decode into the messagestruct
 *****************************************************************************************************/

void PacketReceived()
{
  size_t data_size = cobs.decode(buffer_serial, write - 1, (uint8_t *)decoded_buffer);

  // calculate the CRC only if we have at least three bytes (two CRC, one data)
  if (data_size < 3)
    return;

  uint16_t calc_crc = CRC::Calculate(decoded_buffer, data_size - 2, CRC::CRC_16_CCITTFALSE());

  // struct mower_com *struct_CRC = (struct mower_com *) encoded_buffer;

  if (decoded_buffer[0] == Get_Version && data_size == sizeof(struct msg_get_version))
  {
    struct msg_get_version *message = (struct msg_get_version *)decoded_buffer;
    if (message->crc == calc_crc)
    {
      // valid get_version request, send reply
      struct msg_get_version reply;
      reply.type = Get_Version;
      reply.version = FIRMWARE_VERSION;
      sendMessage(&reply, sizeof(reply));
    }
  }
  else if (decoded_buffer[0] == Set_Buzzer && data_size == sizeof(struct msg_set_buzzer))
  {
    struct msg_set_buzzer *message = (struct msg_set_buzzer *)decoded_buffer;
    if (message->crc == calc_crc)
    {
      // valid set_buzzer request
      Buzzer_set(message->repeat, message->on_time, message->off_time);
    }
  }
  else if (decoded_buffer[0] == Set_LEDs && data_size == sizeof(struct msg_set_leds))
  {
    struct msg_set_leds *message = (struct msg_set_leds *)decoded_buffer;
    if (message->crc == calc_crc)
    {
      // valid set_leds request
      printf("Got valid setled call\n");
#ifdef HW_YF
      leds.set(message->leds);
#else // HW Pico
      mutex_enter_blocking(&mx1);
      LED_activity = message->leds;
      LEDs_refresh(pio_Block1, sm_LEDmux);
      mutex_exit(&mx1);
#endif
    } else {
      printf("Got setled call with crc error\n");
    }
  }
#ifdef YARDFORCE_SUBSCRIPTION_H
  // LowLevel message (if subscribed before)
  else if (decoded_buffer[0] == PACKET_ID_LL_STATUS && data_size == sizeof(struct ll_status))
  {
    struct ll_status *message = (struct ll_status *)decoded_buffer;
    if (message->crc == calc_crc)
    {
      subscription::recv_ll_status = *message; // Valid CRC, deep copy
      subscription::ack();
    }
    else
      printf("Got ll_status packet with crc error\n");
  }
  // HighLevel message (if subscribed before)
  else if (decoded_buffer[0] == PACKET_ID_LL_HIGH_LEVEL_STATE && data_size == sizeof(struct ll_high_level_state))
  {
    struct ll_high_level_state *message = (struct ll_high_level_state *)decoded_buffer;
    if (message->crc == calc_crc)
    {
      subscription::recv_hl_state = *message; // Valid CRC, deep copy
      subscription::ack();
    }
    else
      printf("Got ll_high_level_state packet with crc error\n");
  }
#endif
  else
  {
    printf("some invalid packet\n");
  }

#ifdef _serial_debug_
  printf("packet received with %d bytes : ", (int)data_size);
  uint8_t *temp = decoded_buffer;
  for (size_t i = 0; i < data_size; i++)
  {
    printf("0x%02x , ", *temp);
    temp++;
  }
  printf("\n");
#endif
}

/****************************************************************************************************
 *
 * getDataFromBuffer() read bytes from serial interrupt controlled buffer and couple a string with endcode "00"
 * out to buffer_serial
 *****************************************************************************************************/

void getDataFromBuffer()
{
  while (uart_is_readable(UART_1))
  {
#ifdef HW_YF
    // In (at least) arduinoststm32 uart_getc() is a member of class 'stream' but with different parameters.
    // Don't wanna derive a new subclass. #ifdef is simpler for now and not very hard to read ;-)
    int readbyte = serial_ll.read();
#else
    u_int8_t readbyte = uart_getc(UART_1);
#endif

    buffer_serial[write] = readbyte;
    write++;
    if (write >= bufflen)
    {
      // buffer is full, but no separator. Reset
      write = 0;
      return;
    }
    if (readbyte == 0)
    {
      #ifdef HW_YF
        first_byte_recv = true;
      #endif
      // we have found the packet marker, notify the other core
      PacketReceived();
      write = 0;
      return;
    }
  }
}

#ifndef HW_YF // HW_Pico (HW_YF is arduino based. See setup() & loop() in YardForce/main.h)
int getLedForButton(int button)
{
  if (button >= 4 && button <= 6)
    return 13 - (button - 4);
  if (button >= 8 && button <= 14)
    return 10 - (button - 8);
  return 0;
}

void core1()
{
  printf("Core 1 started\n");
  while (true)
  {
    // Scan Buttons
    bool pressed = false;
    unsigned int button = 0;
    int pressed_count = 0;
    bool allow_hold;

    button = bit_getbutton(1, pressed);

    // Buttons where we allow the hold. The reason for this is, that we have an indicator LED for these buttons.
    allow_hold = (button >= 4 && button <= 6) || (button >= 8 && button <= 14);

    if (button && allow_hold)
    {
      int led = getLedForButton(button);
      // force led off
      mutex_enter_blocking(&mx1);
      Force_LED_off(led, true);
      mutex_exit(&mx1);
      do
      {
        // allow hold, wait for user to hold
        button = bit_getbutton(1000, pressed);
        if (pressed)
        {
          // user indeed held the button
          pressed_count++;
          // if button is still held, we flash and retry
          for (int i = 0; i < pressed_count; i++)
          {
            mutex_enter_blocking(&mx1);
            Blink_LED(pio_Block1, sm_LEDmux, led);
            mutex_exit(&mx1);
          }
        }
      } while (pressed && button != 0 && pressed_count < 2);

      // yes that's a duplicate but we want to wait before releasing the LED, so that's intended.
      if (button && pressed)
      {
        // we're still holding, wait for the button to release. We don't care about the result here.
        bool tmp = pressed; // "... = pressed" assignment is only required for YardForce ports
        bit_getbutton(0, tmp);
      }

      mutex_enter_blocking(&mx1);
      Force_LED_off(led, false);
      mutex_exit(&mx1);
    }
    else
    {
      if (button && pressed)
      {
        // we're still holding, wait for the button to release. We don't care about the result here.
        bool tmp;
        bit_getbutton(0, tmp);
      }
    }

    if (button > 0)
    {

      struct msg_event_button button_msg;
      button_msg.type = Get_Button;
      button_msg.button_id = button;
      button_msg.press_duration = pressed_count;

      sendMessage(&button_msg, sizeof(button_msg));

      // confirm pressed button with buzzer.
      // TODO: on rapid button presses, the FIFO gets full and therefore this call is blocking for a long time.
      mutex_enter_blocking(&mx1);
      buzzer_program_put_words(pio_Block2, sm_buzz, 1, shortbeep * buzzer_SM_CYCLE / 4000, 40);
      mutex_exit(&mx1);

      printf("\n\rsend Button Nr.: %d with count %d", button, pressed_count);
    }
  }
}

int main(void)
{
  uint32_t last_led_update = 0;

  stdio_init_all();

  // setup the second UART 1
  uart_init(UART_1, BAUD_RATE);
  gpio_set_function(UART_TX_PIN, GPIO_FUNC_UART);
  gpio_set_function(UART_RX_PIN, GPIO_FUNC_UART);
  // no flow control
  uart_set_hw_flow(UART_1, false, false);
  uart_set_fifo_enabled(UART_1, true);

  init_button_scan(); // Init hardware for button matix
  // init_LED_driver();

  float ver = (float)FIRMWARE_VERSION / 100.0;
  printf("\n\n\n\rMower Button-LED-Control Version %2.2f\n", ver);

  // initialise state machines
  sm_blink = init_run_StateMachine_blink(pio_Block1);    // on board led alive blink
  sm_LEDmux = init_run_StateMachine_LED_mux(pio_Block1); // LED multiplexer
  sm_buzz = init_run_StateMachine_buzzer(pio_Block2);    // Beeper control

  mutex_enter_blocking(&mx1);
  init_LED_activity();                 // init LED statusmatrix all LEDs off
  LEDs_refresh(pio_Block1, sm_LEDmux); // LED-state to Hardware
  mutex_exit(&mx1);
  sleep_ms(1000);

  // LED blink to say it's alive
  LED_animation(pio_Block1, sm_LEDmux);

  // buzzer say hello
  Buzzer_set(1, 50, 40);

  // Check for button ins permanently pressed e.g. while mounting

  u_int32_t n = keypressed();
  while (n > 0)
  {
    mutex_enter_blocking(&mx1);
    LED_activity = -1;
    LEDs_refresh(pio_Block1, sm_LEDmux);
    mutex_exit(&mx1);
    Buzzer_set(n, 250, 100);

    sleep_ms(10000);
    n = keypressed();
  }

  mutex_enter_blocking(&mx1);
  LED_activity = 0;
  LEDs_refresh(pio_Block1, sm_LEDmux);
  mutex_exit(&mx1);

  // enable other core for button detection
  multicore_reset_core1();
  multicore_launch_core1(core1);

  printf("\n\n waiting for commands or button press");

  while (true)
  {

    getDataFromBuffer();

    uint32_t now = to_ms_since_boot(get_absolute_time());

    // Update the LEDs and their blinking states
    if (now - last_led_update > 10)
    {
      mutex_enter_blocking(&mx1);
      LEDs_refresh(pio_Block1, sm_LEDmux);
      mutex_exit(&mx1);
      last_led_update = now;
    }
  }
}
#endif

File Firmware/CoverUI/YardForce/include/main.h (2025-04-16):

/**
 * @file main.h
 * @author Apehaenger (joerg@ebeling.ws)
 * @brief YardForce CoverUI main header for OpenMower https://github.com/ClemensElflein/OpenMower
 * @version 0.4
 * @date 2023-11-04
 *
 * @copyright Copyright (c) 2023
 *
 */
#ifndef __YARDFORCE_MAIN_H
#define __YARDFORCE_MAIN_H

#include <Arduino.h>  // Stock CoverUI is build now via Arduino framework (instead of HAL), which is ATM the only framework with STM32F030R8 and GD32F330R8 support

#include "datatypes.h"

#if defined(FIRMWARE_VERSION) && !(FIRMWARE_VERSION == 200)
#pragma GCC error "YardForce CoverUI port is based on OM- FIRMWARE_VERSION 200. Port code changes before compiling..."
#include <AbortCompile>
#else
#undef FIRMWARE_VERSION
#endif
#define FIRMWARE_VERSION 206

#if defined(MDL_C500)
#include "../model/C500/assembly.hpp"
#elif defined(MDL_RMECOWV100)
#include "../model/RM-ECOW-V100/assembly.hpp"
#elif defined(MDL_RMECOWV110)
#include "../model/RM-ECOW-V110/assembly.hpp"
#elif defined(MDL_RMEC3V11)
#include "../model/RM-EC3-V11/assembly.hpp"
#elif defined(MDL_SAXPRO)
#include "../model/SAxPRO/assembly.hpp"
#elif defined(MDL_LEGACYHAT)
#include "../model/LegacyHAT/assembly.hpp"
#else
#pragma GCC error "Missing model header!"
#include <AbortCompile>
#endif

#define BATT_ABS_MAX 28.7f
#define BATT_ABS_MIN 21.7f

#define BATT_FULL (BATT_ABS_MAX - 0.3f)
#define BATT_EMPTY (BATT_ABS_MIN + 0.3f)

// STM32/GD32 are single cores, also without threads.
// Send mutex calls of main.cpp to nirvana. Dangerous?
#define auto_init_mutex(name)
#define mutex_enter_blocking(ptr)
#define mutex_exit(ptr)

// OM names. Could also use those, but I prefer logic names instead of physical ones
extern HardwareSerial serial_ll;
#define uart1 &serial_ll

// Some dummy Pico-SDK definitions. Not used but by this we'll NOT pollution original code to much with #ifdefs
#define pio0 NULL
#define pio1 NULL
typedef bool *PIO;
#define buzzer_SM_CYCLE 10800

// Forward declaration for ../main.cpp
extern void buzzer_program_put_words(PIO pio, unsigned int sm, uint32_t repeat, uint32_t duration, uint32_t gap);
extern void uart_putc(HardwareSerial *Serial, uint8_t c);
extern bool uart_is_readable(HardwareSerial *Serial);
extern void Force_LED_off(uint8_t led_num, bool force);

#endif  // __YARDFORCE_MAIN_H

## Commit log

2024-08-23 added LegacyHat support for dumb SC600ECO CoverUI; changed Rain support, since SC600ECO also has Rain sensor
2024-08-23 LegacyHAT CoverUI hardware files
    [Legacy-LedPanel-HAT-B_Cu.gbr, Legacy-LedPanel-HAT-B_Mask.gbr, Legacy-LedPanel-HAT-B_Paste.gbr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]
2024-08-24 exclude KiCAD lock file
2025-04-15 commit before merge
    [Legacy-LedPanel-HAT-v1_1.kicad_sch, Legacy-LedPanel-HAT.kicad_pcb, Legacy-LedPanel-HAT.kicad_sch]
2025-04-16 switched LeghacyHAT to new structure
2025-05-23 HW redesign based on first live tests (new design not tested)
    [Legacy-LedPanel-HAT-2.kicad_sch, Legacy-LedPanel-HAT-v1.kicad_sch, Legacy-LedPanel-HAT.kicad_pcb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]
2026-03-14 last version
    [Legacy-LedPanel-HAT-B_Cu.gbr, Legacy-LedPanel-HAT-B_Mask.gbr, Legacy-LedPanel-HAT-B_Paste.gbr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]

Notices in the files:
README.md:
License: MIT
